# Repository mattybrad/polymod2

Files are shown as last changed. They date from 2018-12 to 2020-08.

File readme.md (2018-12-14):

# PolyMod 2

This is (or will be) an open source modular synthesizer, built using digital rather than analogue technology. This approach retains the flexibility of an analogue modular synth (e.g. Eurorack) while being cheaper to build. Other advantages include polyphony, a free open source database of modules to install, and the ability to save and retrieve patches.

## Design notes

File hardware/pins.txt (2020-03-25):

Arduino pins:
0	read serial from teensy
1	write serial to teensy
2	write address E0
3	write address E1
4	write address E2
5	write address F0
6	write address F1
7	write address F2
8	
9	chip select for address (A to D) shift register
10	chip select for module data (LEDs etc) shift register
11	MOSI to shift registers data in
12	
13	SCK to shift registers SCLK
A0	read analog sensors
A1	read module ID
A2	read patch connections
A3	read/write(?) aux channel
A4	
A5	

NB deliberately grouping ports in this way for fast port manipulation, see https://www.arduino.cc/en/Reference/PortManipulation

Teensy pins required:
Serial in (from Arduino)
Serial out (to Arduino)
Menu inc button
Menu dec button
Menu confirm button
Menu cancel button
I2C pins x2 (used for audio)
Audio pins x5
SPI pins x3 (used for SD + memory, if either in use)
SD select (if in use)
Memory select (if in use)
Analog CV inputs x2(or more I guess)
OLED select
MIDI input

Teensy 4 has now been released so pinout is confirmed, and it looks like it should work fine. Currently have 2 pins spare, could increase that to 3 or 4 by getting omitting extra RAM (can't be bothered with the fiddly soldering, and Teensy 4.0 should have loads more RAM anyway), and possibly by condensing the menu buttons into 3 pins using a shift register (maybe a good idea anyway - could then add more buttons if needed). Extra pins could be used for a PWM CV/audio output (requires two pins for the version in the official library) or maybe two lower-quality single-pin PWM CV outputs. Teensy 4 has no DAC, hence need for PWM CV outs. Could also add a 3rd/4th CV input if really wanting to max out the pins.

Teensy pins:
					3.X													4.0
0					Serial in (from Arduino)		Serial in (from Arduino)
1					Serial out (to Arduino)			Serial out (to Arduino)
2					Menu inc button							Menu inc button
3					Menu dec button							Menu dec button
4					Menu confirm button					Menu confirm button
5					Menu cancel button					Menu cancel button
6					Memory select (optional?)		Memory select (optional?)
7					SPI MOSI										Audio TX
8					OLED select									Audio RX
9					Audio BCLK									OLED select
10				SD card select							SD card select
11				Audio MCLK									SPI MOSI
12				SPI MISO										SPI MISO
13				Audio RX										SPI SCK
14/A0			SPI SCK
15/A1																	MIDI input
16/A2			CV input										CV input
17/A3			CV input										CV input
18/A4			I2C													I2C
19/A5			I2C													I2C
20/A6																	Audio LRCLK
21/A7																	Audio BCLK
22/A8			Audio TX
23/A9			Audio LRCLK									Audio MCLK
-------------------------------------------
24
25
26
27
28
29
30
31/A12		MIDI input
32/A13
33/A14
34/A15
35/A16
36/A17
37/A18	
38/A19	
39/A20
A21/DAC0	CV out 1 (AudioOutputAnalogStereo)
A22/DAC1	CV out 2 (AudioOutputAnalogStereo)

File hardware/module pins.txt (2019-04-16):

MODULE PINS:
1	address C0 (connection test send pin, module ID pin)
2	address C1
3	address C2
4	address F0 (connection test receive pin, analog pin)
5	address F1
6	address F2
7	module ID data
8	analog data
9	connection test send signal
10	connection test receive signal
11	SPI data (to module LEDs etc)
12	SPI clock
13	SPI select
14	power
15	ground
16	aux? spare?

MODULE GROUP PINS:
1	address B0
2	address B1
3	address B2
4	address C0
5	address C1
6	address C2
7	address C3
8	address E0
9	address E1
10	address E2
11	address F0
12	address F1
13	address F2
14	module ID data
15	analog data
16	connection test send signal
17	connection test receive signal
18	SPI data
19	SPI clock
20	power
21	ground
22	aux? spare?

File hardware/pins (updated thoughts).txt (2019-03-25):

Okay, some new thoughts on what the Teensy pins will do. This is a complicated question for a few reasons!
1) Moving from 8 modules to 64 modules requires a bunch more pins
2) Giving the modules more features (especially LED shift registers) requires more pins
3) Giving the synth itself more features (MIDI, OLED display) requires more pins
4) The audio board uses up loads of pins
5) Currently using a Teensy 3.6, which has 40 accessible pins, but likely to move to Teensy 4.0 at some point, which has maybe 24 accessible pins

Ideally I want to get down to 24 pins, to make things future-proof, so let's start from there.

Things that probably can't be multiplexed (7 pins):
MIDI in
Module ID data
Patch cable data
Analogue sensor data
Auxiliary data
CV in
CV out (but maybe no DAC on T4)

Things that can probably be shift-registered:
Address A (3 pins)
Address B (3 pins)
Address C (3 pins)
Address D (3 pins)

Things that can maybe be shift-registered:
Address E (3 pins)
Address F (3 pins)

Shift register pins needed (unclear, maybe 5 pins?):
Clock (shared)
Latch (module LEDs etc)
Latch (addressing, maybe shareable...?)
Module LED data
Addressing data

Audio board pins (12 pins):
Audio (7 pins, 2 shareable with other I2C)
SD and memory (5 pins)

OLED can hopefully share pins with audio board (I2C)

If I haven't forgotten anything, that gives us the following possibilities:

If all the address pins get shifted and OLED is shareable: 24 pins (dead on)

The issue with this is that shifting the addressing might not be fast enough, which would leave a few options:
1) Abandon support for Teensy 4, stick with Teensy 3.6 (and deal with the fact that it won't be able to power loads of modules)
2) Free up pins for at least channel F by ditching certain features, perhaps aux channel or CV in/out (additional note: the MCP4921 DAC runs on SPI, which could potentially share with the audio board)
3) Move the less cerebral features to an Arduino, perhaps something like the following:

Rough guess Arduino pins:
0-1: serial comms
2-6: shift registers for addressing A, B, C, D, and module LEDs
7-12: direct addressing of E, F
13: module ID
A0-A5: analog sensors, aux, anything else

That would actually work pretty nicely and free up both pins and runtime on the Teensy. Tempting!

This Arduino solution would also play nicely with the idea of multiple Teensys for more processing power, although the Teensy 4 may make this pointless anyway. Yes, actually, let's put that idea to bed now, this project is complicated enough as it is!

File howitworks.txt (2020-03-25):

Here's how the system will work, as of Aug 28th 2019:

PolyMod 2 will be a synthesizer system that can physically fit in a Eurorack case, be powered by a Eurorack power supply, and have some limited connectivity with Eurorack modules (maybe two audio ins/outs and two CV ins/outs), but for the most part it is electrically incompatible and separate from the Eurorack system.

PM2 will consist of a master module, with various other modules connected to it. The master module will have ports to connect up to 14 modules - more can be added with expander modules.

The modules in the PM2 system will be patchable like Eurorack modules, but will use breadboard jumper wires. The patching is done physically and sends a digital signal to the master module, which updates an onboard soft synth with the patching data.

The master module contains a Teensy 4.0 for audio processing and a Teensy LC to handle the physical interface (patching, knobs, LEDs, etc).

The Teensy LC (currently using an Arduino but will upgrade soon) scans every patch point on every module. There are 8 groups of modules, each containing up to 8 modules, giving a total of 64 (although 2 modules are used up by the master module). It also reads all the knobs and buttons, and writes to any LEDs.

The Teensy LC communicates with the Teensy 4.0 via serial. Possible messages are as follows:

END LOOP (command 0) - signifies the end of one cycle of updates, no other data needed.
PATCH CONNECTION (command 1) - signifies that a patch cable is connected. Contains 6 bytes of data: the group number, module number, and socket number for both ends of the patch cable.
ANALOG READING (command 2)
MODULE ID READING (command 3)

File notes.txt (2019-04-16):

26/3/2019 - tried serial communication between arduino and teensy. used a voltage divider to step 5V arduino output down to 2.5V (10k resistor either side of divider), which worked fine with teensy. at 9600(whatever that unit is), was able to send 300 messages per second from arduino and receive them all fine on teensy. at 115200 was able to send >6000 messages per second, which is hopefully plenty. the messages were ~5 bytes each so basically sending/receiving at the proper rate, i.e. can send 115200 bits per second. oh, apparently you can actually go way higher than this, so that's good, because sending 64 lots of 8 10-bit analog values would eat up a lot of data - you could only do it 22 times per second (although maybe that's just about acceptable?). anyway, ought to think of a clever way to compress the data and not send unused channels, but hopefully can just crank the baud rate to something huge regardless.
can also happily send data the other way, just did a direct link between the two, 3.3V output into 5V input worked fine.

8/4/2019 - back from holiday! built a test circuit with an arduino, simulating two modules in separate module groups. the concept of module groups works fine, and i'm now into the problem of speed. with 2 module groups (16 modules total) reading connections and analog data, the entire loop is done in around 2.5 seconds, although the "important" time to note is for the inner loop to process - this takes under 20ms. this is already almost acceptable. however, increasing the number of module groups has a huge impact on speed. 8 full module groups (64 modules) take ~40 seconds(!) to process, with an unacceptable (but not quite as horrendous) 100ms or so for the inner loop. all of this is without any optimisations, however. port manipulation could give a drastic improvement. something weird is happening with pin numbers, but it's late and i'll figure it out another time.

9/4/2019 - okay, the weird problem was a combination of wiring multiplexers up in the wrong order and then getting the channel numbers the wrong way round in the code - all good now though. to confirm, "naive" time benchmark (i.e. with no port manipulation, and checking everything regardless of whether a module is present and has 8 knobs) for max 16 modules is about 2.5 seconds for checking connections and 18ms for checking knobs, although i haven't yet simulated module ID checking (okay to be slow) or shift reg sending for LEDs etc (needs to be pretty fast really). should be fine, though.
haven't yet tested serial communication of connection info to the teensy, but should be trivial.

okay, new info - turns out that the analogRead call was taking up most of the time. can now read all connections in 450ms, all live data in 4ms. most modules won't use all 8 analogRead calls so that's not a huge problem, but worth investigating speedier analogRead methods. apparently there's something called "ADC free running mode"...

meanwhile, it's worth noting that 32 modules can now be read (sans analog) in 1800ms/7ms, 48 modules in 4100ms/11ms, and 64 modules in 7200ms/14ms. basically, we can seemingly crank up the number of modules pretty high and the only thing that suffers hugely is connection testing speed.

okay, after some further testing and optimisation using port manipulation, 64 modules can now by read (without analog) in 2000ms/3ms, which is really really good. naively adding the analogRead line back in bumps it up from 2 seconds to 30 seconds, so that's definitely the next priority. could also almost double the current speed (without analog) by using port manipulation on the shift registers, but this is a bit more complex maybe.

right, here are all the things i've done to get the speed as high as possible:
- increased the serial baud rate
- moved some variable declarations from global to local
- replaced multiplication with bitwise operators
- used port manipulation for the most-switched channels (E and F)
- controlled shift registers via SPI
- probably some other stuff i've forgotten
and the end result is a frankly spectacular 1000ms/1ms for 64 modules! still without analog, but that's a job for another day.

9/4/19 - big success! tried out a version of the ADC free-running method and it works. 64-module time with analog is now ~2s for a full reading and ~60ms for a full loop. timings are now a bit more vague because ADC free-running mode means that some values don't get read for a few cycles, but i added a fallback to make the sketch wait if a value hasn't been checked for N cycles.

12/4/19 - tested module shift register, which will be used for sending binary data to modules, mainly for LEDs but potentially for anything at all. time for 64 modules increased to ~3s, but that's fine because a) it's not that slow and b) not many modules will probably end up using this functionality.

15/4/19 - starting to figure out serial communication. doing it naively certainly slows things down a fair bit, so i'm going to have to try and be clever.

16/4/19 - right! arduino can now send all signals (patch connection, analog reading, module ID) to teensy with a full loop time of around 3.4s for 64 modules, and something like 8ms (max 80ms) for the inner loop. this is fine for now - it gives us a baseline. analog readings are currently only 8-bit not 10-bit - we'll see whether that feels okay once we're doing some actually music. had to reduce resolution because you kinda need to store all the analog values in the arduino sketch (so you can compare them with previous values and only send if they change), but the arduino's memory is (ironically) pretty "teensy". maybe an argument to switch to a teensy LC for this task. anyway, we've got a proof of concept. next step is maybe to get some actual synthesis happening (connecting/disconnecting patches, changing values with knobs, etc), just to check everything works in a slightly more "real world" way (is there noticeable latency? does it feel responsive? etc).

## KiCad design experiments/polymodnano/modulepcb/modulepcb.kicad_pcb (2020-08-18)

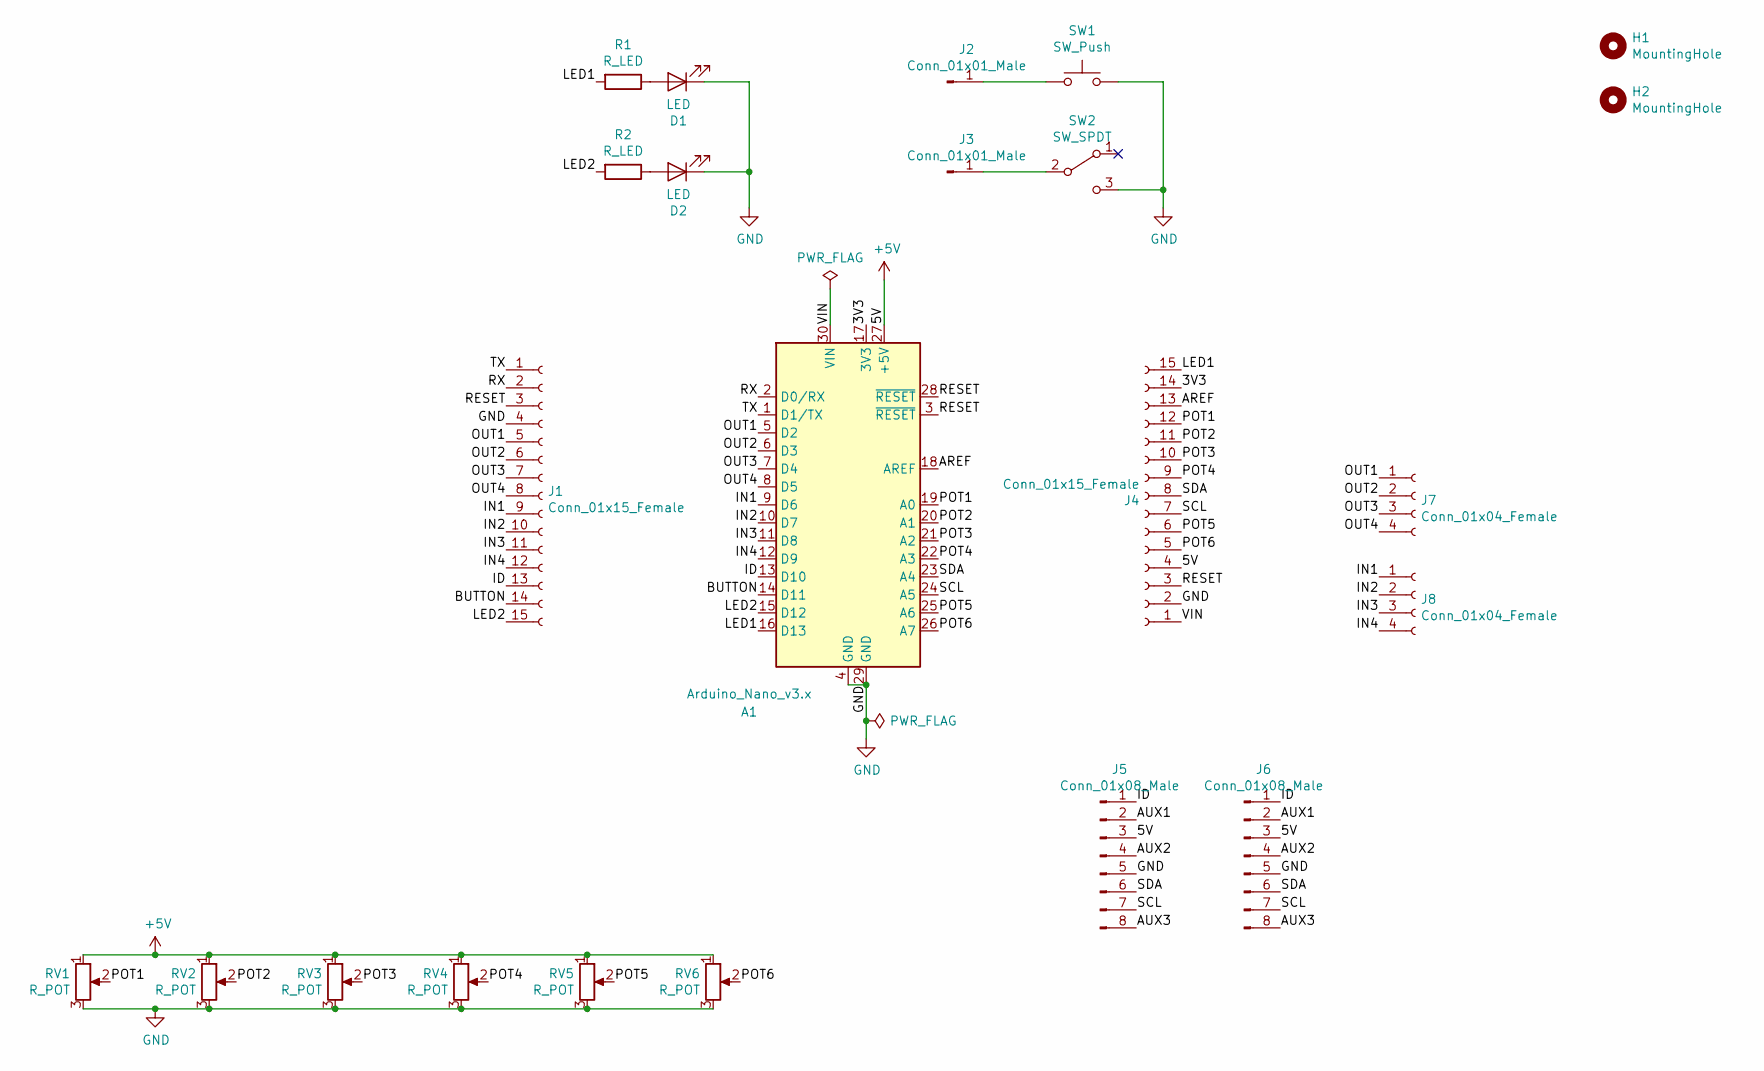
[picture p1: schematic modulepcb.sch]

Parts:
A1: Arduino_Nano_v3.x; Arduino_Nano
D1, D2: LED; LED_D5.0mm
H1, H2: MountingHole; MountingHole_3.2mm_M3
J1, J4: Conn_01x15_Female; PinHeader_1x15_P2.54mm_Vertical
J2, J3: Conn_01x01_Male; PinHeader_1x01_P2.54mm_Vertical
J5, J6: Conn_01x08_Male; PinHeader_1x08_P2.54mm_Vertical
J7, J8: Conn_01x04_Female; PinSocket_1x04_P2.54mm_Vertical
R1, R2: R_LED; R_Axial_DIN0204_L3.6mm_D1.6mm_P7.62mm_Horizontal
RV1, RV2, RV3, RV4, RV5, RV6: R_POT; Potentiometer_Alps_RK09K_Single_Vertical
SW1: SW_Push; SW_PUSH-12mm_Wuerth-430476085716
SW2: SW_SPDT; EG1206

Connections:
+5V: A1.27 (+5V), J4.4, J5.3, J6.3, RV1.1, RV2.1, RV3.1, RV4.1, RV5.1, RV6.1
/3V3: A1.17 (3V3), J4.14
/AREF: A1.18 (AREF), J4.13
/AUX1: J5.2, J6.2
/AUX2: J5.4, J6.4
/AUX3: J5.8, J6.8
/BUTTON: A1.14 (D11), J1.14
/ID: A1.13 (D10), J1.13, J5.1, J6.1
/IN1: A1.9 (D6), J1.9, J8.1
/IN2: A1.10 (D7), J1.10, J8.2
/IN3: A1.11 (D8), J1.11, J8.3
/IN4: A1.12 (D9), J1.12, J8.4
/LED1: A1.16 (D13), J4.15, R1.2
/LED2: A1.15 (D12), J1.15, R2.2
/OUT1: A1.5 (D2), J1.5, J7.1
/OUT2: A1.6 (D3), J1.6, J7.2
/OUT3: A1.7 (D4), J1.7, J7.3
/OUT4: A1.8 (D5), J1.8, J7.4
/POT1: A1.19 (A0), J4.12, RV1.2
/POT2: A1.20 (A1), J4.11, RV2.2
/POT3: A1.21 (A2), J4.10, RV3.2
/POT4: A1.22 (A3), J4.9, RV4.2
/POT5: A1.25 (A6), J4.6, RV5.2
/POT6: A1.26 (A7), J4.5, RV6.2
/RESET: A1.3 (~RESET), A1.28 (~RESET), J1.3, J4.3
/RX: A1.2 (D0/RX), J1.2
/SCL: A1.24 (A5), J4.7, J5.7, J6.7
/SDA: A1.23 (A4), J4.8, J5.6, J6.6
/TX: A1.1 (D1/TX), J1.1
/VIN: A1.30 (VIN), J4.1
GND: A1.4 (GND), A1.29 (GND), D1.1 (K), D2.1 (K), J1.4, J4.2, J5.5, J6.5, RV1.3, RV2.3, RV3.3, RV4.3, RV5.3, RV6.3, SW1.2, SW2.3 (C)
unnamed: D1.2 (A), R1.1
unnamed: D2.2 (A), R2.1
unnamed: J2.1, SW1.1
unnamed: J3.1, SW2.2 (B)

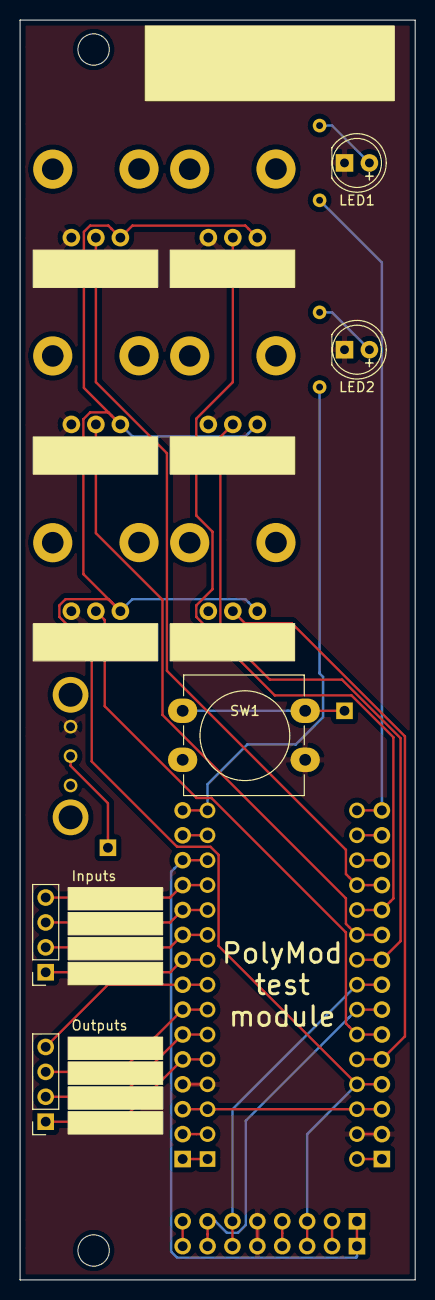
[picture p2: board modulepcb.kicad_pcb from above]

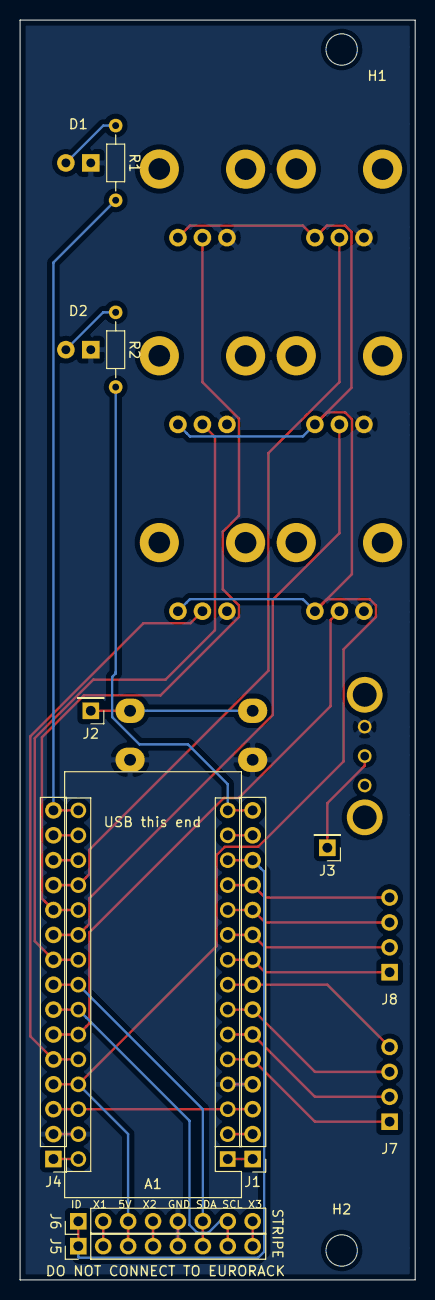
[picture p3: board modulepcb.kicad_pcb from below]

Board: 2 copper layers, 40.3 x 128.5 mm, 23 parts (9 on the bottom side), 35 nets.

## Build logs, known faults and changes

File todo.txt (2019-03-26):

- build test circuit with arduino reading from different modules in different groups and exchanging data with teensy. will require perhaps 10 4051s (ugh), send/rcv for root, group 1, group 2, module 1 and module 2. if concept seems to work, focus on improving speed, see whether 64 modules is viable. run intense audio sketch on teensy during comms.

- add MIDI input to test setup

- buy and test an OLED screen, incorporate into test setup, including menu buttons

- add CV in and out circuitry, test with eurorack setup

- if everything seems good, design the PCB - this project is probably out of the scope of breadboard..? polymod v0 was breadboard, that had 8 modules, each with 3 4051s, plus 2(?) root 4051s, total of 26ish. a working prototype of polymod v2 might need... 6 root 4051s, 12 group 4051s (for 2 groups), 6 or 12 4051s for the master module, 6 4051s for a test module, total of up to 36! could maybe get rid of aux chips, down to 30, then also make second group just a send/rcv group, down to 27... basically it's do-able but pretty hardcore.

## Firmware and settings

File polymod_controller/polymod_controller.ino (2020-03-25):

//  This code is for an Arduino Uno which will read analog/digital data from up to 64 modules and transmit it via serial connection to a Teensy 3.X
//  Currently it's a mess.

#include <SPI.h>

// High when a value is ready to be read
volatile int readFlag;

// Value to store analog result
volatile int analogVal;

const int addressE[] = {2,3,4};
const int addressF[] = {5,6,7};
const int readConnections = A2;

byte analogReadings[8][8][8];

//const int maxConnections = 512; // max total number of patch cables

void setup() {
  Serial.begin(500000);
  pinMode(9,OUTPUT);
  pinMode(10,OUTPUT);
  pinMode(11,OUTPUT);
  pinMode(13,OUTPUT);
  for(int i=0;i<3;i++) {
    pinMode(addressE[i], OUTPUT);
    pinMode(addressF[i], OUTPUT);
  }
  pinMode(readConnections, INPUT_PULLUP);
  SPI.begin();

  // code adapted from http://www.glennsweeney.com/tutorials/interrupt-driven-analog-conversion-with-an-atmega328p

  // clear ADLAR in ADMUX (0x7C) to right-adjust the result
  // ADCL will contain lower 8 bits, ADCH upper 2 (in last two bits)
  ADMUX &= B11011111;
  
  // Set REFS1..0 in ADMUX (0x7C) to change reference voltage to the
  // proper source (01)
  ADMUX |= B01000000;
  
  // Clear MUX3..0 in ADMUX (0x7C) in preparation for setting the analog
  // input
  ADMUX &= B11110000;
  
  // Set MUX3..0 in ADMUX (0x7C) to read from AD8 (Internal temp)
  // list of possible inputs is available in Table 24-4 of the ATMega328
  // datasheet
  ADMUX |= 0;
  // ADMUX |= B00001000; // Binary equivalent
  
  // Set ADEN in ADCSRA (0x7A) to enable the ADC.
  // Note, this instruction takes 12 ADC clocks to execute
  ADCSRA |= B10000000;
  
  // Set ADATE in ADCSRA (0x7A) to enable auto-triggering.
  ADCSRA |= B00100000;
  
  // Clear ADTS2..0 in ADCSRB (0x7B) to set trigger mode to free running.
  // This means that as soon as an ADC has finished, the next will be
  // immediately started.
  ADCSRB &= B11111000;
  
  // Set the Prescaler to 128 (16000KHz/128 = 125KHz)
  // Above 200KHz 10-bit results are not reliable.
  ADCSRA |= B00000111;
  
  // Set ADIE in ADCSRA (0x7A) to enable the ADC interrupt.
  // Without this, the internal interrupt will not trigger.
  ADCSRA |= B00001000;
  
  // Enable global interrupts
  // AVR macro included in <avr/interrupts.h>, which the Arduino IDE
  // supplies by default.
  sei();
  
  // Kick off the first ADC
  readFlag = 0;
  // Set ADSC in ADCSRA (0x7A) to start the ADC conversion
  ADCSRA |=B01000000;
}

unsigned long lastStart = 0;
unsigned long innerStart = 0;
unsigned long innerEnd = 0;
int numGroups = 2;
byte cyclesSinceRead[8*8*8];
bool firstLoop = true;

void loop() {
  //Serial.println("START");
  bool thingFailed = false;
  lastStart = millis();
  Serial.write(0); // new loop started
  int shiftData = 0; // 2-byte value to send to shift register
  for(byte a=0;a<numGroups;a++) {
    // set multiplexer to route connection test voltage to group A

    for(byte b=0;b<8;b++) {
      // if more than one module group...
      // send A/B address byte to shift register (via SPI for speed)
      
      // set multiplexer to route connection test voltage to group A, module B
      
      for(byte c=0;c<8;c++) {
        // set multiplexeter to route connection test voltage to group A, module B, socket C

        if(c==0) innerStart = millis();
        
        for(byte d=0;d<numGroups;d++) {
          // if more than one module group...
          // set multiplexer to route ID number data from group D
          // set multiplexer to route connection readings from group D
          // set multiplexer to route analog readings from group D
          // set multiplexer to route shift register latch to group D (for shift out, not shift in)
          // set multiplexer to route auxiliary data from group D (either from shift register or multiplexer)
          
          shiftData = (d<<9)+(c<<6)+(b<<3)+a;
          digitalWrite(10,LOW);
          SPI.transfer((shiftData>>8));
          SPI.transfer(shiftData);
          digitalWrite(10,HIGH);

          //Serial.print("OUTPUT TO SHIFT REGISTERS: ");
          //Serial.println(shiftData, BIN);

          //delay(1000);
          
          for(byte e=0;e<8;e++) {
            // set multiplexer to route ID number data from group D, module E
            // set multiplexer to route connection readings from group D, module E
            // set multiplexer to route analog readings from group D, module E
            // set multiplexer to route shift register latch to group D, module E (for shift out, not shift in)
            // set multiplexer to route auxiliary data from group D, module E (either from shift register or multiplexer)
    
            // if applicable, send binary data to group D, module E shift register (for LEDs etc)
            digitalWrite(9,LOW);
            SPI.transfer(B10101010);
            digitalWrite(9,HIGH);
    
            // if applicable, read binary data from group D, module E via shift register (switches, buttons, etc)
            //digitalWrite(addressE[0],bitRead(e,0));
            //digitalWrite(addressE[1],bitRead(e,1));
            //digitalWrite(addressE[2],bitRead(e,2));
            
            for(byte f=0;f<8;f++) {
              // set multiplexer to route ID number data from group D, module E, switch F
              // set multiplexer to route connection reading from group D, module E, socket F
              // set multiplexer(s) to route analog reading from group D, module E, channel F, including auxiliary multiplexer if used

              // read ID number data (group D, module E, bit F)
              // something like bitWrite(moduleIDReadings[d*8+e], f, digitalRead(MODULE_ID_PIN));
    
              // read whether module A, socket B, is connected to group D, module E, socket F
    
              // read analog data from group D, module E, channel F
    
              // if applicable, read analog data from auxiliary multiplexer on group D, module E, channel F
    
              // read serial data from MIDI port

              if(a==0&&b==0&&c==0&&d==0&&e==0&&f==0) {
                // test dummy data, send module ID data
                Serial.write(3); // ID message
                Serial.write(0); // group number
                Serial.write(2); // module number
                Serial.write(136); // module ID
              }

              int socket1 = (a<<6)+(b<<3)+c;
              int socket2 = (d<<6)+(e<<3)+f;
              bool doDelay = true;

              if(socket1 < socket2) {

                //digitalWrite(addressF[0],bitRead(f,0));
                //digitalWrite(addressF[1],bitRead(f,1));
                //digitalWrite(addressF[2],bitRead(f,2));
                PORTD = (e<<2) + (f<<5); // faster "port manipulation" version version of commented-out lines above
                
                //delayMicroseconds(6); // if there is a suitable, slowish task to be done, could do it here instead of delay?
                // do analog stuff here for now
              }
              
              if(readFlag == 1) {
                //analogValues[socket2] = analogVal;
                cyclesSinceRead[socket2] = 0;
                readFlag = 0;
                //int testVal = analogVal;
                //sendAnalogMessage(d,e,f,analogVal);
                //analogReadings[d][e][f] = analogVal>>2;
                doDelay = !updateAnalogReading(d,e,f,analogVal>>2);
              } else {
                cyclesSinceRead[socket2]++;
                if(cyclesSinceRead[socket2] > 10) {
                  while(readFlag != 1) {
                    // wait
                  }
                  cyclesSinceRead[socket2] = 0;
                  readFlag = 0;
                  //int testVal = analogVal;
                  //analogReadings[d][e][f] = analogVal>>2;
                  doDelay = !updateAnalogReading(d,e,f,analogVal>>2);
                }
              }
              if(doDelay) delayMicroseconds(10); // was 6, but was getting errors

              if(socket1 < socket2) {
                if(!bitRead(PINC,2)) {
                  //Serial.print(socket1);
                  //Serial.print("->");
                  //Serial.println(socket2);
                  Serial.write(1); // patch connection message
                  Serial.write(a);
                  Serial.write(b);
                  Serial.write(c);
                  Serial.write(d);
                  Serial.write(e);
                  Serial.write(f);
                  //Serial.write('\n');
                }
              }
            }
          }
        }
        firstLoop = false;
        // send all analog values as serial message
        //Serial.write(2);
        for(int i=0;i<8;i++) {
          for(int j=0;j<8;j++) {
            for(int k=0;k<8;k++) {
              //Serial.write(analogReadings[i][j][k]);
            }
          }
        }
        //Serial.write('\n'); // end serial message
        if(c==0) innerEnd = millis();
      }
    }
  }
  /*Serial.println(" ");
  Serial.print("ALL MODULES TIME: ");
  Serial.println(innerEnd - innerStart);
  Serial.print("TOTAL TIME: ");
  Serial.println(millis() - lastStart);
  Serial.println(thingFailed?"FAILED":"SUCCEEDED");*/
}

bool updateAnalogReading(byte group,byte module,byte pin,byte reading) {
  byte oldReading = analogReadings[group][module][pin];
  int diff = reading - oldReading;
  if(abs(diff)>=2 || firstLoop) {
    analogReadings[group][module][pin] = reading;
    Serial.write(2); // analog message
    Serial.write(group); // group
    Serial.write(module); // module
    Serial.write(pin); // pin
    Serial.write(reading); // reading
    return true;
  } else {
    return false;
  }
}

// Interrupt service routine for the ADC completion
ISR(ADC_vect){

  // Done reading
  readFlag = 1;
  
  // Must read low first
  analogVal = ADCL | (ADCH << 8);
  
  // Not needed because free-running mode is enabled.
  // Set ADSC in ADCSRA (0x7A) to start another ADC conversion
  // ADCSRA |= B01000000;
}

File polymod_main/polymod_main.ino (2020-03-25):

// required for teensy audio
#include <Audio.h>
#include <Wire.h>
#include <SPI.h>
#include <SD.h>
#include <SerialFlash.h>

// other libraries
#include <Bounce2.h>

// monitor RAM
#include <cstdint>
#include "RamMonitor.h"
RamMonitor ram;
uint32_t reporttime;

// include classes
#include "PhysicalModule.h"
#include "Master.h"
#include "PhysicalPatchCable.h"
#include "VirtualPatchCable.h"
#include "Menu.h"

// include Constants
#include "Constants.h"

// include specific modules - this part can be generated automatically
// AUTO GENERATED INCLUDE STATEMENTS GOES HERE

// define constants
#define MAX_MODULES 64
#define MAX_POLYPHONY 4
#define MAX_SOCKETS 512
#define MAX_CABLES 200

// define pins
#define DEC_BUTTON_PIN 2
#define INC_BUTTON_PIN 3
#define YES_BUTTON_PIN 4
#define NO_BUTTON_PIN 5

// more definitions
byte moduleIDReadings[MAX_MODULES];
PhysicalPatchCable patchCableConnections[MAX_CABLES]; // main array of physically connected patch cables
PhysicalPatchCable newPatchCableConnections[MAX_CABLES]; // most recently updated array of connected patch cables, to check for new connections/disconnections
VirtualPatchCable virtualPatchCableConnections[MAX_CABLES];
int newConnectionIndex = 0;
PhysicalModule physicalModules[MAX_MODULES]; // all physical modules
AudioControlSGTL5000 sgtl; // teensy audio board chip
Menu menu = Menu();

// buttons
Bounce incButton = Bounce();
Bounce decButton = Bounce();
Bounce yesButton = Bounce();
Bounce noButton = Bounce();

// serial stuff
byte nextPosition = 0;
byte currentCommand[8];
float tempFreq = 100.0;
unsigned long lastLoop;
unsigned long thisLoop;

void setup() {
  // init RAM reporting
  ram.initialize();
  while(!Serial);
  reporttime = millis();

  Serial1.begin(500000);
  Serial.begin(500000);
  incButton.attach(INC_BUTTON_PIN,INPUT_PULLUP);
  decButton.attach(DEC_BUTTON_PIN,INPUT_PULLUP);
  yesButton.attach(YES_BUTTON_PIN,INPUT_PULLUP);
  noButton.attach(NO_BUTTON_PIN,INPUT_PULLUP);
  incButton.interval(25);
  decButton.interval(25);
  yesButton.interval(25);
  noButton.interval(25);

  // init audio board
  AudioMemory(50);
  sgtl.enable();
  sgtl.volume(0.3);

  // init test modules
  physicalModules[0].virtualModule = new Master();
  physicalModules[8].virtualModule = new TestOscillator();
}

void loop() {
  // report RAM usage every 2 seconds
  uint32_t time = millis();
  if((time - reporttime) > 2000) {
    reporttime = time;
    //report_ram();
  };
  ram.run();

  while(Serial1.available()) {
    byte thisByte = Serial1.read();
    if(nextPosition==0) {
      // new command!
      currentCommand[0] = thisByte;
      if(thisByte>0) nextPosition ++; // don't increment position for command 0 because it doesn't have any other data expected
      else {
        updatePatchCableConnections();
      }
    } else {
      currentCommand[nextPosition] = thisByte;
      switch(currentCommand[0]) {
        case 1:
        nextPosition++;
        if(nextPosition>6) {
          nextPosition=0;
          addNewPatchCableConnection((currentCommand[1]<<6)+(currentCommand[2]<<3)+currentCommand[3],(currentCommand[4]<<6)+(currentCommand[5]<<3)+currentCommand[6]);
        }
        break;

        case 2:
        // analog reading (currently 8-bit, upgrade to 10-bit at some point)
        nextPosition++;
        if(nextPosition>4) {
          nextPosition=0;
          /*Serial.print("ANALOG READING: ");
          Serial.print(currentCommand[1]);
          Serial.print("-");
          Serial.print(currentCommand[2]);
          Serial.print("-");
          Serial.print(currentCommand[3]);
          Serial.print(": ");
          Serial.println(currentCommand[4]);*/
          if(currentCommand[1]==0&&currentCommand[2]==0&&currentCommand[3]==0) tempFreq = 100.0 + 10*currentCommand[4];
        }
        break;

        case 3:
        // module ID reading
        nextPosition++;
        if(nextPosition>3) {
          nextPosition=0;
          moduleIDReadings[(currentCommand[1]<<3)+currentCommand[2]] = currentCommand[3];
          /*Serial.print("MODULE ID READING: ");
          Serial.print(currentCommand[1]);
          Serial.print("-");
          Serial.print(currentCommand[2]);
          Serial.print(": ");
          Serial.println(currentCommand[3]);*/
        }
        break;
      }
    }
  }

  // menu button update code (probably not the best place for this, remnant from earlier code, fix later)
  incButton.update();
  decButton.update();
  yesButton.update();
  noButton.update();
  if(incButton.fell()) {
    menu.incrementValue();
  } else if(decButton.fell()) {
    menu.decrementValue();
  } else if(yesButton.fell()) {
    menu.confirm();
  } else if(noButton.fell()) {
    menu.cancel();
  }
}

void updatePhysicalModuleList() {
  bool anyChanges = false;
  // temp - add dummy module
  moduleIDReadings[8] = 136;
  moduleIDReadings[3] = 88;
  moduleIDReadings[4] = 99;
  moduleIDReadings[2] = 0;
  // skip position 0, reserved for master module
  for(int i=1; i<MAX_MODULES; i++) {
    if(moduleIDReadings[i] == 0) {
      // no physical module present
      if(physicalModules[i]==NULL) {
        // no change
      } else {
        // module has been removed - destroy physical module object
        delete physicalModules[i];
        physicalModules[i]=NULL;
        anyChanges= true;
      }
    } else {
      // physical module present
      if(physicalModules[i]->id==moduleIDReadings[i]) {
        // no change
      } else {
        // module has been added - create new physical module object
        physicalModules[i] = new PhysicalModule(moduleIDReadings[i]);
        anyChanges = true;
      }
    }
  }
  if(anyChanges) updateVirtualPatchCables(); // possibly unnecessary? but shouldn't break anything
}
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

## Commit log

2018-12-19 started the teensy code and began thinking about pin numbers
2018-12-22 couple more planning comments, off home for xmas!
2019-03-25 initial schematic design and fraught thoughts about pin allocation
    [polymod2.kicad_pcb, polymod2.sch]
2019-04-09 big speed boost from using ADC free-running mode
2019-04-17 physical patch cable detection working
2019-08-28 resurrecting the polymod 2 project - it kinda works!
    [mainboard.kicad_pcb, mainboard.sch, polymod2.sch]
2019-09-03 now trying to implement patch cables properly - getting there...
2019-09-03 actually working with real circuit patching!
2019-09-03 cable disconnection now works
2019-09-04 tried to get variable polyphony working and broke everything
    [VirtualPatchCable.cpp]
2019-09-04 fixed silly mistake, polyphony values between 1 and 4 now work well
    [PhysicalPatchCable.cpp, VirtualPatchCable.cpp, polymod_main.ino]
2019-09-04 can now have up to 8 notes polyphony, but memory usage starting to be a problem?
    [polymod_main.ino]
2019-09-05 patch cables can now access any input or output in audiostreams, vco modulation working
2019-09-05 filter is working
2020-03-25 oops haven't committed for ages
    [testsmt.kicad_pcb, testsmt.sch]
2020-08-17 started module schematic
    [modulepcb.kicad_pcb, modulepcb.sch]
2020-08-17 First test for OSC and Python I2C communication with Arduino module
2020-08-18 created 8hp test module
    [modulepcb.kicad_pcb, modulepcb.sch]
2020-08-18 pcb done
    [modulepcb-B_Cu.gbr, modulepcb-B_Mask.gbr, modulepcb-B_Paste.gbr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]
2020-08-20 messing about with teensy code again
2020-08-20 teensy reading knobs
2020-08-21 more good teensy experiments
2020-08-27 i keep crashing the teensy
    [fakeserialmain.ino, teensymain.ino]
2020-08-28 implemented volt per octave on oscillatornode
2020-09-01 arduinos talking to chrome via midi
2020-09-05 knobs working, leds working
